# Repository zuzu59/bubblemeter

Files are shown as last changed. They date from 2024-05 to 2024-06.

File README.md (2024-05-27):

# bubblemeter
Petit projet pour mesurer les bulles d'un barboteur lors d'une fermentation de bière

zf240527.1430

## Buts
Mesurer en continu la production de bulles du barboteur pendant la fermentation de la bière afin de pouvoir mesurer la progression !

## Problématique
La fermentation de la bière doit se faire sans oxygène, il est donc exclu d'ouvrir le fermenteur pour pouvoir vérifier l'état de la fermentation. D'où l'idée ici, de faire un petit appareil électronique qui mesure le débit des bulles lors de la fermentation.

La fermentation va aussi évoluer en fonction de la température extérieure, cela sera intéressant de pouvoir la corréler avec le débit des bulles !

## Moyens
On va utiliser un petit détecteur de *barrières* infrarouge pour mesurer le passage des bulles dans le barboteur et un esp32-c3 super mini pour le MCU pour envoyer le débit sur un MQTT via le WIFI.

## En cours de rédaction ****************

## Sources
### Sources xxxx 
xxxx

### yyyy
yyyy

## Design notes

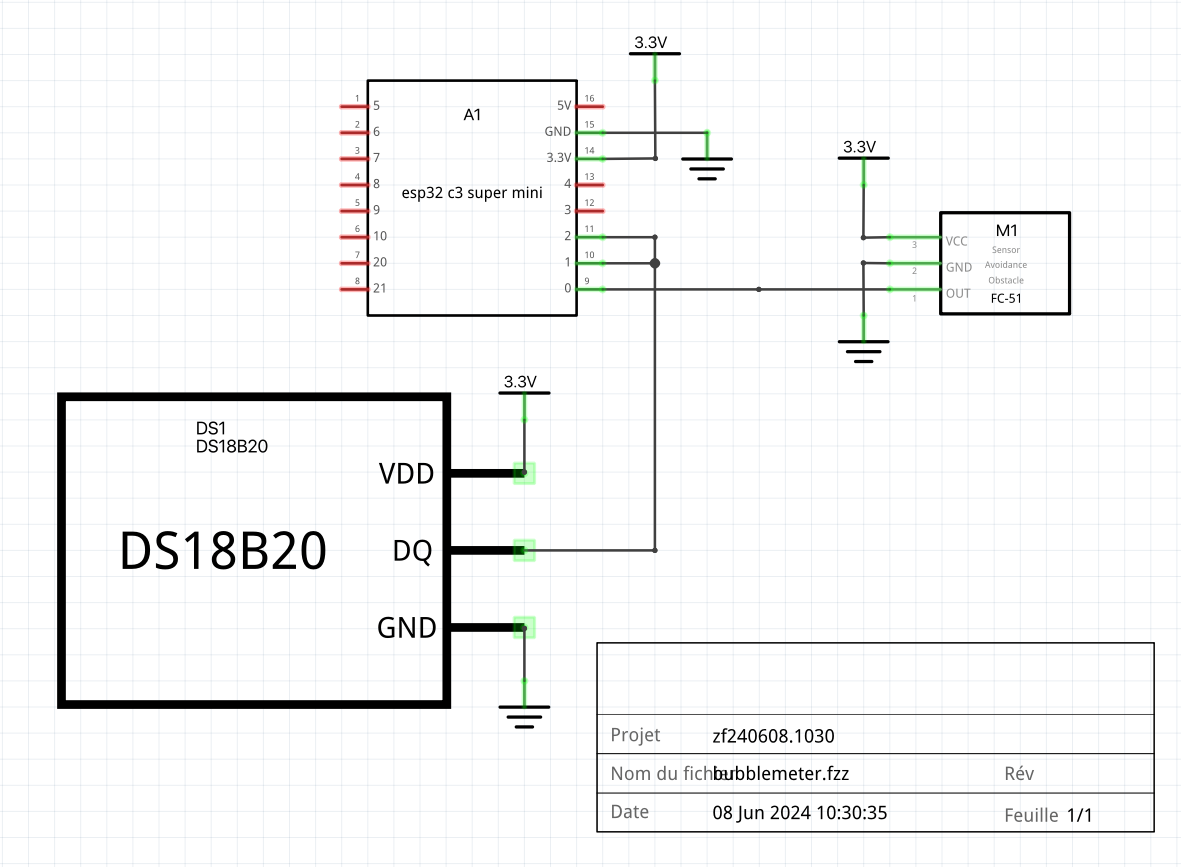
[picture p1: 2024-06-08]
schema/schema.png

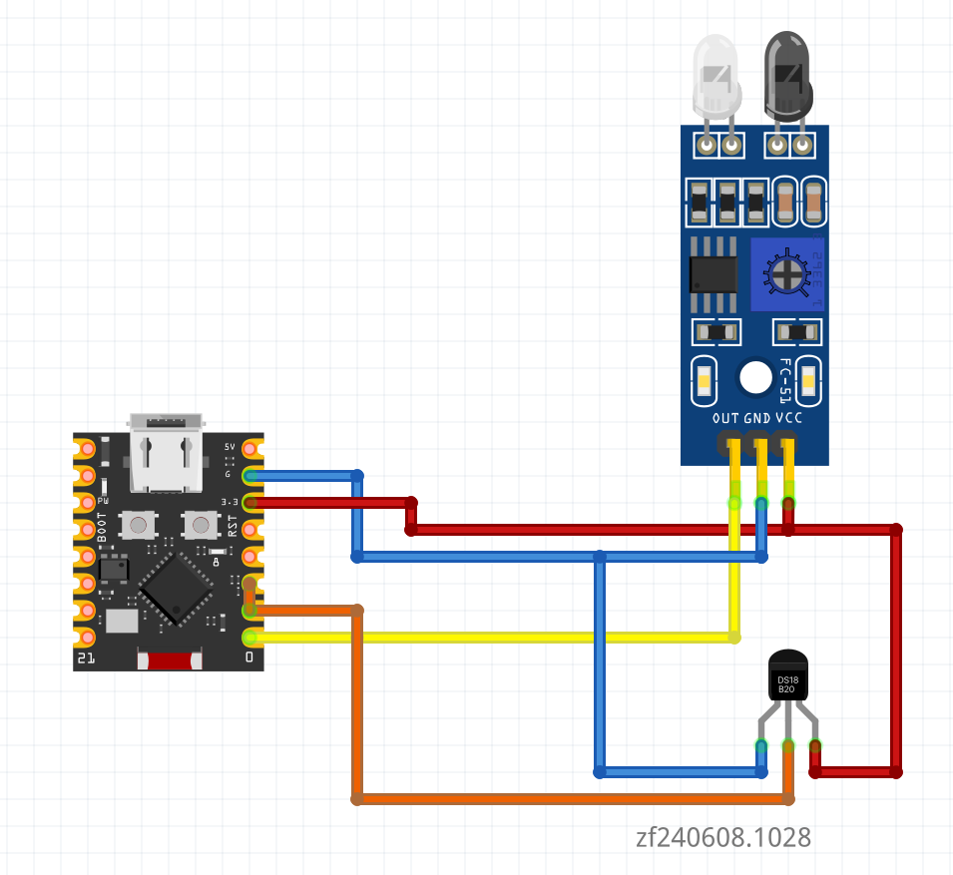
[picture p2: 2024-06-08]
schema/breadboard.png

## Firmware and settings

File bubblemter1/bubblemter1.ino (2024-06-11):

// Petit projet pour mesurer les bulles d'un barboteur lors d'une fermentation de bière
//
// ATTENTION, ce code a été testé sur un esp32-c3. Pas testé sur les autres boards !
//
#define zVERSION        "zf240611.1056"
#define zHOST           "bblmter1"              // ATTENTION, tout en minuscule
#define zDSLEEP         0                       // 0 ou 1 !
#define zTIME_TO_SLEEP  120                     // dSleep en secondes 
int zDelay1Interval =   60000;                   // Délais en mili secondes pour la boucle loop

#define DEBUG true                              // A décommenter si on veut des prints console pour le debug

/*
Utilisation:

Astuce:

Installation:

Pour les esp32-c3 super mini, il faut:
 * choisir comme board ESP32C3 Dev Module
 * disabled USB CDC On Boot et utiliser USBSerial. au lieu de Serial. pour la console !
 * changer le schéma de la partition à Minimal SPIFFS (1.9MB APP with OTA/190kB SPIFFS)

Pour le WiFiManager, il faut installer cette lib depuis le lib manager sur Arduino:
https://github.com/tzapu/WiFiManager

Pour le senseur DS18B20 il faut installer ces lib: 
https://github.com/PaulStoffregen/OneWire                             OneWire
https://github.com/milesburton/Arduino-Temperature-Control-Library    DallasTemperature

Pour MQTT, il faut installer la lib (home-assistant-integration):
https://github.com/dawidchyrzynski/arduino-home-assistant

Pour JSON, il faut installer cette lib:
https://github.com/bblanchon/ArduinoJson

Sources:
https://www.reddit.com/r/esp32/comments/1crwakg/built_in_temperature_sensor_on_esp32c3_red_as/?rdt=63263
https://forum.fritzing.org/t/need-esp32-c3-super-mini-board-model/20561
https://www.aliexpress.com/item/1005006005040320.html
https://randomnerdtutorials.com/esp32-useful-wi-fi-functions-arduino
https://dronebotworkshop.com/wifimanager/
https://lastminuteengineers.com/esp32-ota-web-updater-arduino-ide/
https://github.com/dawidchyrzynski/arduino-home-assistant/blob/main/examples/sensor-integer/sensor-integer.ino
https://chat.mistral.ai/    pour toute la partie API REST et wifiAuto ᕗ
https://lastminuteengineers.com/handling-esp32-gpio-interrupts-tutorial/
https://www.aliexpress.com/item/1005006579276114.html
*/




// #define DEBUG true
// #undef DEBUG



// General
const int ledPin = 8;               // the number of the LED pin
const int buttonPin = 9;            // the number of the pushbutton pin

const int pulsePin = 0;             // la pin pour le détecteur de proximité (interruption)
int zPulsesCounter = 0;              // compteur de pulses


// Sonar Pulse
#include "zSonarpulse.h"


// WIFI
#include "zWifi.h"


// OTA WEB server
#include "otaWebServer.h"


// MQTT
#include "zMqttBubblemter1.h"


// Temperature sensor
#include "zTemperatureBubblemter1.h"

RTC_DATA_ATTR int bootCount = 0;
#if zDSLEEP == 1
  // Deep Sleep
  #define uS_TO_S_FACTOR 1000000  /* Conversion factor for micro seconds to seconds */
  // #define zTIME_TO_SLEEP  300      /* Time ESP32 will go to sleep (in seconds) */
#endif


// Compteur de bulles
unsigned long zPulseRebondMillis = 250;  
unsigned long zPulseNextMillis = 0; 

void IRAM_ATTR zPulseInterrupt() {
  if (millis() > zPulseNextMillis){
    ++zPulsesCounter;
    zPulseNextMillis = millis() + zPulseRebondMillis;
#ifdef DEBUG
    USBSerial.print(zPulsesCounter);
    USBSerial.println(", Y'a une bulle !");
#endif
  }
}


void setup() {
  // Il faut lire la température tout de suite au début avant que le MCU ne puisse chauffer !
  initDS18B20Sensor();
  delay(200);
  readSensor();

  // Pulse deux fois pour dire que l'on démarre
  pinMode(ledPin, OUTPUT);
  digitalWrite(ledPin, LOW); delay(zSonarPulseOn); digitalWrite(ledPin, HIGH); delay(zSonarPulseOff);
  digitalWrite(ledPin, LOW); delay(zSonarPulseOn); digitalWrite(ledPin, HIGH); delay(zSonarPulseOff);
  delay(zSonarPulseWait);

  // Start serial console
  USBSerial.begin(19200);
  USBSerial.setDebugOutput(true);       //pour voir les messages de debug des libs sur la console série !
  delay(3000);                          //le temps de passer sur la Serial Monitor ;-)
  USBSerial.println("\n\n\n\n**************************************\nCa commence !"); USBSerial.println(zHOST ", " zVERSION);

  #if zDSLEEP == 1
    //Increment boot number and print it every reboot
    ++bootCount;
    sensorValue4 = bootCount;
    USBSerial.println("Boot number: " + String(bootCount));
    // Configuration du dsleep
    esp_sleep_enable_timer_wakeup(zTIME_TO_SLEEP * uS_TO_S_FACTOR);
    USBSerial.println("Setup ESP32 to sleep for every " + String(zTIME_TO_SLEEP) + " Seconds");
  #endif

  // Start WIFI
  zStartWifi();
  sensorValue3 = WiFi.RSSI();

  // Start OTA server
  otaWebServer();

  // Connexion au MQTT
  USBSerial.println("\n\nConnect MQTT !\n");
  ConnectMQTT();

  // go go go
  USBSerial.println("\nC'est parti !\n");

  #if zDSLEEP == 1
    // Envoie toute la sauce !
    zEnvoieTouteLaSauce();
    USBSerial.println("\nC'est envoyé !\n");

    // Partie dsleep. On va dormir !
    USBSerial.println("Going to sleep now");
    delay(200);
    USBSerial.flush(); 
    esp_deep_sleep_start();
    USBSerial.println("This will never be printed");
  #endif

  // Initialise le compteur de bulles
	pinMode(pulsePin, INPUT_PULLUP);
	// attachInterrupt(pulsePin, zPulseInterrupt, FALLING);
	attachInterrupt(pulsePin, zPulseInterrupt, RISING);

}


void loop() {
  // Envoie toute la sauce !
  zEnvoieTouteLaSauce();

  // Délais non bloquant pour le sonarpulse et l'OTA
  zDelay1(zDelay1Interval);
}


// Envoie toute la sauce !
void zEnvoieTouteLaSauce(){
  // Juste pour voir s'il est toujours vivant sur home assistant ;-)
  ++bootCount;
  sensorValue4 = bootCount;

  // Récupère l'état du compteur de bulles
  sensorValue1 = zPulsesCounter;

  // Calcul le débit des bulles
  sensorValue2 = zPulsesCounter * 60 * 1000 / zDelay1Interval;
#ifdef DEBUG
  // USBSerial.print(sensorValue2);
  // USBSerial.println(" bulles par minutes !");
#endif
  zPulsesCounter = 0;

  // Lit les températures
  readSensor();

  // Envoie les mesures au MQTT
  sendSensorMqtt();

  // Graphe sur l'Arduino IDE les courbes des mesures
  USBSerial.print("sensor1:");
  USBSerial.print(sensorValue1);
  USBSerial.print(",sensor2:");
  USBSerial.print(sensorValue2);
  USBSerial.print(",sensor3:");
  USBSerial.print(sensorValue3);
  USBSerial.print(",sensor4:");
  USBSerial.print(sensorValue4);
  USBSerial.print(",sensor5:");
  USBSerial.print(sensorValue5);
  USBSerial.println("");
}


// Délais non bloquant pour le sonarpulse et l'OTA
void zDelay1(long zDelayMili){
  long zDelay1NextMillis = zDelayMili + millis(); 
  while(millis() < zDelay1NextMillis ){
    // OTA loop
    server.handleClient();
    // Un petit coup sonar pulse sur la LED pour dire que tout fonctionne bien
    sonarPulse();
  }
}

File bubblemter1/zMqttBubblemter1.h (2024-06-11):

// zf240611.1022

float sensorValue1 = 0;  // variable to store the value coming from the sensor 1
float sensorValue2 = 0;  // variable to store the value coming from the sensor 2
float sensorValue3 = 0;  // variable to store the value coming from the sensor 3
float sensorValue4 = 0;  // variable to store the value coming from the sensor 4
float sensorValue5 = 0;  // variable to store the value coming from the sensor 5
#define TEMP_CELSIUS 0


// MQTT
#include <ArduinoHA.h>
#define DEVICE_NAME      zHOST               // toujours en minuscules !
#define SENSOR_NAME1     "BubbleCounter"
#define SENSOR_NAME2     "BubbleMeter"
#define SENSOR_NAME3     "RSSI"
#define SENSOR_NAME4     "BootCount"
#define SENSOR_NAME5     "Temp_DS18B20"

#define PUBLISH_INTERVAL  2000 // how often image should be published to HA (milliseconds)

HADevice device(DEVICE_NAME);                // c'est le ID du device, il doit être unique !
HAMqtt mqtt(client, device);
unsigned long lastUpdateAt = 0;

// c'est le ID du sensor, il doit être unique !
HASensorNumber Sensor1(DEVICE_NAME SENSOR_NAME1);   // c'est le nom du sensor sur MQTT ! (PrecisionP1=x.1, PrecisionP2=x.01, ...)
HASensorNumber Sensor2(DEVICE_NAME SENSOR_NAME2, HASensorNumber::PrecisionP2);   // c'est le nom du sensor sur MQTT ! (PrecisionP1=x.1, PrecisionP2=x.01, ...)
HASensorNumber Sensor3(DEVICE_NAME SENSOR_NAME3);   // c'est le nom du sensor sur MQTT !
HASensorNumber Sensor4(DEVICE_NAME SENSOR_NAME4);   // c'est le nom du sensor sur MQTT !
HASensorNumber Sensor5(DEVICE_NAME SENSOR_NAME5, HASensorNumber::PrecisionP1);   // c'est le nom du sensor sur MQTT ! (PrecisionP1=x.1, PrecisionP2=x.01, ...)

static void ConnectMQTT() {
    device.setName(DEVICE_NAME);                // c'est le nom du device sur Home Assistant !
    mqtt.setDataPrefix(DEVICE_NAME);             // c'est le nom du device sur MQTT !
    device.setSoftwareVersion(zVERSION);
    device.setManufacturer("espressif");
    device.setModel("esp32-c3 super mini");

    Sensor1.setIcon("mdi:gauge");
    Sensor1.setName(SENSOR_NAME1);           // c'est le nom du sensor sur Home Assistant !
    Sensor1.setUnitOfMeasurement("bbl");

    Sensor2.setIcon("mdi:gauge");
    Sensor2.setName(SENSOR_NAME2);           // c'est le nom du sensor sur Home Assistant !
    Sensor2.setUnitOfMeasurement("b/mn");

    Sensor3.setIcon("mdi:wifi-strength-1");
    Sensor3.setName(SENSOR_NAME3);           // c'est le nom du sensor sur Home Assistant !
    Sensor3.setUnitOfMeasurement("dBm");

    Sensor4.setIcon("mdi:counter");
    Sensor4.setName(SENSOR_NAME4);           // c'est le nom du sensor sur Home Assistant !
    Sensor4.setUnitOfMeasurement("sum");

    Sensor5.setIcon("mdi:thermometer");
    Sensor5.setName(SENSOR_NAME5);           // c'est le nom du sensor sur Home Assistant !
    Sensor5.setUnitOfMeasurement("°C");

    mqtt.begin(BROKER_ADDR, BROKER_USERNAME, BROKER_PASSWORD);
    USBSerial.println("MQTT connected");
}

// Envoie les senseurs au mqtt
void sendSensorMqtt(){
    mqtt.loop();
    Sensor1.setValue(sensorValue1);
    Sensor2.setValue(sensorValue2);
    Sensor3.setValue(sensorValue3);
    Sensor4.setValue(sensorValue4);
    if (sensorValue5 > -50){                // Test si le capteur DS18B20 est présent ?
      Sensor5.setValue(sensorValue5);
    }
}

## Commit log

2024-05-27 firstcommit: récupéré le code du densimètre et épuré pour le bubblemeter. Pour l'instant il n'y a que la température interne qui fonctionne sur le MQTT
    [densimetre.fzz]
2024-06-07 firstcommit: j'ai mis comme base de code mon thermomètre lowcost pour démarrer. Cela va me permettre de pouvoir le flasher plus facilement via OTA et d'avoir déjà 95% du code de fait \o/
2024-06-07 new: YEAH, cela compte bien les bulles \o/
2024-06-07 new: voilà, mon débimètre à bulles fonctionne \o/ reste encore à l'envoyer sur le MQTT de Home Assistant ᕗ
2024-06-08 change: changé la façon de mesurer le débit des bulles. Aussi refactorisé la partie MQTT
2024-06-08 change: n'envoie plus de donnée à home assistant quand il n'y a pas de capteur DS18B20
2024-06-08 new: envoie les données à home assistant \o/
2024-06-08 new: réalisé le schéma du bubblemeter \o/
    [bubblemeter.fzz, densimetre.fzz]
2024-06-08 new: le capteur de température DS18B20 est fonctionnel. Mon bullomètre est donc terminé et prêt à être testé \o/
2024-06-08 new: ajouter le bootcount pour voir combien de fois j'ai envoyé des valeurs à home assistant depuis le boot
2024-06-11 change: remplacé la température interne par l'état du compteur de bulles
